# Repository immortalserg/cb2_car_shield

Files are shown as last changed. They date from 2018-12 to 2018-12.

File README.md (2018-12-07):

# cb2 car shield

Шилд для Cubieboard2 (или Banana Pi M1, M1+, M3, M2M, R2, M64, M2 Ultra, M2 Berry, Nanopi A64) и LCD панели LQ123K1LG03 под этот шлейф (разъем J1) или этот шлейф (разъем J2)

### Разъемы для подключения LVDS

Omron XF2M-4015-1A - 40 контактный BananaPi M3, A64, M2B, M2U, R2 (разъем J4), M1, M1+ (разъем J5)

Omron XF2M-2415-1A - 24 контактный BananaPi M2M (разъем J3)

Omron XF2M-3015-1A - 30 контактный NanoPi A64 (разъем J6)

### Описание

Разъемы Omron применены для того, чтобы не задумываться над расположением разъема так как стандартные разъемы (например Hirose) имеют одностороннее подключение шлейфа в отличии от Omron у которого двухстороннее подключение шлейфа.

Миникомпьютер предназначен для вывода информации на экран, по уарт к миникомпьютеру подключен микроконтроллер Atmel SAM3X8E (Arduino DUE) который считывает данные и по uart передает на миникомпьютер , входы к микроконтроллеру подключены через буферы MC14503B (цифровые порты 22-52), цифровые порты 8-12 можно использовать как ШИМ и 53 как I/O запаяв перемычки или как входы запаяв микросхему. Аналоговые порты 0-7 для подключения датчиков через делители.

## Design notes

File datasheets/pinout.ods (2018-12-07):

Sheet: LQ123K1LG03
LQ123K1LG03 | CB2Car | СВ2Car2 | CB2
1 | 1 | 1 | 44 | +3.3V |  | Parameter | Symbol | Min. | Typ. | Max. | Unit
2 | 2 | 2 |  | +3.3V |  | Frequency | 1/T c | 40 | 53.172 | 56 | MHz
 | 3 |  |  |  |  | Horizontal period | T H | 1420 | 1688 | 1895 | clock
 | 4 |  |  |  |  |  |  | 25.4 | 31.746 | 47.4 | μs
3 | 5 | 5 |  | GND |  | Horizontal period (High) | T Hd | 1280 | 1280 | 1280 | clock
4 | 6 | 6 |  | GND |  | Vertical period | T V | 487 | 525 | 575 | line
5 | 7 | 7 | 13 | RXIN0- | Receiver signal, CH0 (－) |  |  | - | 16.7 | - | ms
6 | 8 | 8 | 1 | RXIN0+ | Receiver signal, CH0 (＋) | Vertical period (High) | T Vd | 480 | 480 | 480 | line
7 | 9 | 13 | 2 | GND | GND
8 | 10 | 9 | 15 | RXIN1- | Receiver signal, CH1 (－)
9 | 11 | 10 | 3 | RXIN1+ | Receiver signal, CH1 (＋)
10 | 12 | 14 | 9 | GND | GND
 | 13
 | 14
11 | 15 | 11 | 17 | RXIN2- | Receiver signal, CH2 (－)
12 | 16 | 12 | 5 | RXIN2+ | Receiver signal, CH2 (＋)
 | 17
 | 18
13 | 19 |  | 20 | GND | GND
14 | 20 | 15 | 19 | RXCLK- | IN- Receiver signal, CK
15 | 21 | 16 | 7 | RXCLK+ | IN+ Receiver signal, CK
16 | 22 |  |  | GND | GND
17 | 23 | 17 | 11 | RXIN3- | Receiver signal, CH3 (－)
18 | 24 | 18 | 21 | RXIN3+ | Receiver signal, CH3 (＋)
 | 25
 | 26
19 | 27 | 19 |  | RL/UD | Horizontal/Vertical display mode select signal [Note1]
20 | 28 | 20 |  | SELLVDS | SELLVDS
 | 29
 | 30
https://ru.aliexpress.com/item/LVDS-CABLE-DF14-20-S6-double-2ch-6bit-for-12inch-15inch-lcd-panel/32624039545.html

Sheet: BPi
BananaPi |  |  |  |  |  |  |  |  |  |  |  |  |  |  |  |  | NanoPi
F2 | M1 | M1+ | M2 Zero | M2+ | M2B | M2M | M2M | M2U | M3 | M64 | P2 Zero | R1 | R2 | R64 | W2 | Zero | A64
 | A20 | A20 |  |  | R40 | A33 | R16 | R40 | A83T | A53 |  |  | MT7623N |  |  |  | A64 |  |  | Processor
 |  |  |  |  |  |  |  |  |  |  |  |  |  |  |  |  |  |  | Тип 1 |  |  | Тип 2 |  |  | Тип 3 |  |  | Тип 4 |  |  | Тип 5 |  | Тип 6
 |  |  |  |  |  |  |  |  |  |  |  |  |  |  |  |  |  |  | GPIO DIP40-254
 |  | 5 |  |  |  | 4 | 3 |  | 2 |  | 1 |  |  |  |  |  | 6 | 1 |  | 3.3V |  |  | 3.3V |  |  | 3.3V |  |  | 3.3V |  |  | 3.3V |  | SYS_3.3V
 |  | 5 |  |  |  | 4 | 3 |  | 2 |  | 1 |  |  |  |  |  | 6 | 2 |  | 5.0V |  |  | 5.0V |  |  | 5.0V |  |  | 5.0V |  |  | 5.0V |  | VDD_5V
 |  | 5 |  |  |  | 4 | 3 |  | 2 |  | 1 |  |  |  |  |  | 6 | 3 | PA12 | TWI0-SDA |  | PH5 | TWI2-SDA |  | PH5 | TWI1-SDA |  | PH5 | SDA |  | PB21 | TWI2-SDA | E15 | I2C2_SDA
 |  | 5 |  |  |  | 4 | 3 |  | 2 |  | 1 |  |  |  |  |  | 6 | 4 |  | 5.0V |  |  | 5.0V |  |  | 5.0V |  |  | 5.0V |  |  | 5.0V |  | VDD_5V
 |  | 5 |  |  |  | 4 | 3 |  | 2 |  | 1 |  |  |  |  |  | 6 | 5 | PA11 | TWI0-SCK |  | PH4 | TWI2-SCK |  | PH4 | TWI1-SCK |  | PH4 | SCL |  | PB20 | TWI2-SCK | E14 | I2C2_SCL
 |  | 5 |  |  |  | 4 | 3 |  | 2 |  | 1 |  |  |  |  |  | 6 | 6 |  | GND |  |  | GND |  |  | GND |  |  | GND |  |  | GND |  | GND
 |  | 5 |  |  |  | 4 | 3 |  | 2 |  | 1 |  |  |  |  |  | 6 | 7 | PA6 | PWM1 |  | PL10 | S-PWM |  | PH1 | PWM1 |  | PH1 | PWM |  | PI3 | PWM1 | D7
 |  | 5 |  |  |  | 4 | 3 |  | 2 |  | 1 |  |  |  |  |  | 6 | 8 | PA13 | UART3-TX | SPI1-CS | PB0 | UART2-TX |  | PB0 | UART2-TX |  | PB0 | UART0-TX |  | PH0 | UART3\_TX | H4 | UART3-TX
 |  | 5 |  |  |  | 4 | 3 |  | 2 |  | 1 |  |  |  |  |  | 6 | 9 |  | GND |  |  | GND |  |  | GND |  |  | GND |  |  | GND |  | GND
 |  | 5 |  |  |  | 4 | 3 |  | 2 |  | 1 |  |  |  |  |  | 6 | 10 | PA14 | UART3-RX | SPI1-CLK | PB1 | UART2-RX |  | PB1 | UART2-RX |  | PB1 | UART0-RX |  | PH1 | UART3\_RX | H5 | UART3-RX
 |  | 5 |  |  |  | 4 | 3 |  | 2 |  | 1 |  |  |  |  |  | 6 | 11 | PA1 | UART2-RX |  | PC4 | PC4 |  | PH6 | UART3\_TX |  | PH6 | UART3_TX |  | PI19 | UART2\_RX | B0 | UART2-TX
 |  | 5 |  |  |  | 4 | 3 |  | 2 |  | 1 |  |  |  |  |  | 6 | 12 | PA16 | UART3-CTS | SPI1-MISO | PB3 | UART2-CTS |  | PB3 | UART2-CTS |  | PG11 | PCM-BITCLK |  | PH2 | PH2 | L10 | PWM_S
 |  | 5 |  |  |  | 4 | 3 |  | 2 |  | 1 |  |  |  |  |  | 6 | 13 | PA0 | UART2-TX |  | PC7 | PC7 |  | PH7 | UART3\_RX |  | PH7 | UART3_RX |  | PI18 | UART2\_TX | L8 | I2C_S_SCL
 |  | 5 |  |  |  | 4 | 3 |  | 2 |  | 1 |  |  |  |  |  | 6 | 14 |  | GND |  |  | GND |  |  | GND |  |  | GND |  |  | GND |  | GND
 |  | 5 |  |  |  | 4 | 3 |  | 2 |  | 1 |  |  |  |  |  | 6 | 15 | PA3 | UART2-CTS |  | PC17 | PC17 |  | PG12 | AP-PCM-DOUT |  | PD21 | LVDS_V1N | IO-15 | PI17 | UART2\_CTS | L9 | I2C_S_SDA
 |  | 5 |  |  |  | 4 | 3 |  | 2 |  | 1 |  |  |  |  |  | 6 | 16 | PA15 | UART3-RTS | SPI1-MOSI | PB22 | UART2-RTS |  | PB2 | UART2-RTS |  | PB2 | UART0-RTS |  | PH20 | CAN\_TX | H6 | UART3-RTS
 |  | 5 |  |  |  | 4 | 3 |  | 2 |  | 1 |  |  |  |  |  | 6 | 17 |  | VCC-3V3 |  |  | VCC-3V3 |  |  | VCC-3V3 |  |  | 3.3V |  |  | VCC-3V3 |  | SYS_3.3V
 |  | 5 |  |  |  | 4 | 3 |  | 2 |  | 1 |  |  |  |  |  | 6 | 18 | PC4 | PC4 |  | PL8 | PL8 |  | PG11 | AP-PCM-CLK |  | PB3 | UART0-CTS |  | PH21 | CAN\_RX | H7 | UART3-CTS
 |  | 5 |  |  |  | 4 | 3 |  | 2 |  | 1 |  |  |  |  |  | 6 | 19 | PC0 | SPI0-MOSI |  | PC0 | SPI0_MOSI |  | PC0 | SPI0\_MOSI |  | PC0 | SPI-MOSI |  | PI12 | SPI0\_MOSI | C0 | SPI0-MOSI
 |  | 5 |  |  |  | 4 | 3 |  | 2 |  | 1 |  |  |  |  |  | 6 | 20 |  | GND |  |  | GND |  |  | GND |  |  | GND |  |  | GND |  | GND
 |  | 5 |  |  |  | 4 | 3 |  | 2 |  | 1 |  |  |  |  |  | 6 | 21 | PC1 | SPI0-MISO |  | PC1 | SPI0_MISO |  | PC1 | SPI0\_MISO |  | PC1 | SPI-MISO |  | PI13 | SPI0\_MISO | C1 | SPI0-MISO
 |  | 5 |  |  |  | 4 | 3 |  | 2 |  | 1 |  |  |  |  |  | 6 | 22 | PA2 | UART2-RTS |  | PL9 | PL9-EINT9 |  | PG10 | AP-PCM-SYNC |  | PD20 | IO-22 | LVDS_V1P | PI16 | UART2\_RTS | B1 | UART2-RX
 |  | 5 |  |  |  | 4 | 3 |  | 2 |  | 1 |  |  |  |  |  | 6 | 23 | PC2 | SPI0-CLK |  | PC2 | SPI0_CLK |  | PC2 | SPI0\_CLK |  | PC2 | SPI-CLK |  | PI11 | SPI0\_CLK | C2 | SPI0-CLK
 |  | 5 |  |  |  | 4 | 3 |  | 2 |  | 1 |  |  |  |  |  | 6 | 24 | PC3 | SPI0-CS |  | PC3 | SPI0_CS |  | PC3 | SPI0\_CS |  | PC3 | SPI-CE0 | SPI0_CS | PI10 | SPI0\_CS0 | C3 | SPI0-CS
 |  | 5 |  |  |  | 4 | 3 |  | 2 |  | 1 |  |  |  |  |  | 6 | 25 |  | GND |  |  | GND |  |  | GND |  |  | GND |  |  | GND |  | GND
 |  | 5 |  |  |  | 4 | 3 |  | 2 |  | 1 |  |  |  |  |  | 6 | 26 | PC7 | PC7 |  | PH10 | PH10 |  | PG13 | AP-PCM-DIN |  | PD25 | SPI-CE1 | LVDS_VCN | PI14 | SPI0\_CS1 | H8 | SPDIF-OUT
 |  | 5 |  |  |  | 4 | 3 |  | 2 |  | 1 |  |  |  |  |  | 6 | 27 | PA19 | TWI1-SDA |  | PH3 | TWI1-SDA |  | PD19 | LVDS\_V0N |  | PD19 | ID-SD | LVDS_V0N | PI1 | TWI3-SDA | H3 | I2C1_SDA
 |  | 5 |  |  |  | 4 | 3 |  | 2 |  | 1 |  |  |  |  |  | 6 | 28 | PA18 | TWI1-SCK |  | PH2 | TWI1-SCK |  | PL11 | PL11-EINT11 |  | PD24 | ID-SC | LVDS_VCP | PI0 | TWI3-SCK | H2 | I2C1_SCL
 |  | 5 |  |  |  | 4 | 3 |  | 2 |  | 1 |  |  |  |  |  | 6 | 29 | PA7 | PA7-EINT7 |  | PC18 | PC18 |  | PD18 | LVDS\_V0P |  | PD18 | IO-29 | LVDS_V0P | PB5 | I2S\_MCLK | H10
 |  | 5 |  |  |  | 4 | 3 |  | 2 |  | 1 |  |  |  |  |  | 6 | 30 |  | GND |  |  | GND |  |  | GND |  |  | GND |  |  | GND |  | GND
 |  | 5 |  |  |  | 4 | 3 |  | 2 |  | 1 |  |  |  |  |  | 6 | 31 | PA8 | PA8-EINT8 |  | PG10 | I2S1-BCLK | UART3-TX | PD21 | LVDS\_V1N |  | PD23 | IO-31 | LVDS_V2N | PB6 | I2S\_BCLK | H11
 |  | 5 |  |  |  | 4 | 3 |  | 2 |  | 1 |  |  |  |  |  | 6 | 32 | PL2 | PL2-S-EINT2 |  | PG13 | I2S1-DIN | UART3-CTS | PD23 | LVDS\_V2N |  | PD22 | IO-32 | LVDS_V2P | PB12 | I2S\_DI | D4
 |  | 5 |  |  |  | 4 | 3 |  | 2 |  | 1 |  |  |  |  |  | 6 | 33 | PA9 | PA9-EINT9 |  | PG11 | I2S1-LRCK | UART3-RX | PD20 | LVDS\_V1P |  | PD27 | IO-33 | LVDS_V3N | PB7 | I2S\_LRCK | D5
 |  | 5 |  |  |  | 4 | 3 |  | 2 |  | 1 |  |  |  |  |  | 6 | 34 |  | GND |  |  | GND |  |  | GND |  |  | GND |  |  | GND |  | GND
 |  | 5 |  |  |  | 4 | 3 |  | 2 |  | 1 |  |  |  |  |  | 6 | 35 | PA100 | PA10-EINT10 |  | PG12 | I2S1-DOUT | UART3-RTS | PD25 | LVDS\_VCN |  | PG10 | PCM-LRCLK | PCM-SYNC | PB8 | I2S\_DO0 | D3 | SPI1-MISO
 |  | 5 |  |  |  | 4 | 3 |  | 2 |  | 1 |  |  |  |  |  | 6 | 36 | PL4 | PL4-S-EINT4 |  | PE5 | PE5 |  | PD22 | LVDS\_V2P |  | PD26 | IO-36 | LVDS_V3P | PI21 | UART7\_RX | D0 | SPI1-CS
 |  | 5 |  |  |  | 4 | 3 |  | 2 |  | 1 |  |  |  |  |  | 6 | 37 | PA17 | PA17-EINT17 | SPDIF-OUT | PE4 | PE4 |  | PD24 | LVDS\_VCP |  | PL11 | IO-37 | EINT11 | PB3 | IR0\_TX | D6
 |  | 5 |  |  |  | 4 | 3 |  | 2 |  | 1 |  |  |  |  |  | 6 | 38 | PA21 | PA21-EINT21 |  | PE18 | OWA-DOUT |  | PD27 | LVDS\_V3N |  | PG13 | PCM-DIN |  | PI20 | UART7\_TX | D2 | SPI1-MOSI
 |  | 5 |  |  |  | 4 | 3 |  | 2 |  | 1 |  |  |  |  |  | 6 | 39 |  | GND |  |  | GND |  |  | GND |  |  | GND |  |  | GND |  | GND
 |  | 5 |  |  |  | 4 | 3 |  | 2 |  | 1 |  |  |  |  |  | 6 | 40 | PA20 | PA20-EINT20 |  | PE19 | PE19 |  | PD26 | LVDS\_V3P |  | PG12 | PCM-DO |  | PB13 | SPDIF\_DO | D1 | SPI1-CLK
 |  |  |  |  |  |  |  |  |  |  |  |  |  |  |  |  |  |  | DSI FPC24-05PH-BOT
 |  |  |  |  |  | 2 | 1 |  |  |  |  |  |  |  |  |  |  | 1 |  | DSI-D0N |  |  | DSI-D0N
 |  |  |  |  |  | 2 | 1 |  |  |  |  |  |  |  |  |  |  | 2 |  | DSI-D0P |  |  | DSI-D0P
 |  |  |  |  |  | 2 | 1 |  |  |  |  |  |  |  |  |  |  | 3 |  | DSI-D1N |  |  | DSI-D1N
 |  |  |  |  |  | 2 | 1 |  |  |  |  |  |  |  |  |  |  | 4 |  | DSI-D1P |  |  | DSI-D1P
 |  |  |  |  |  | 2 | 1 |  |  |  |  |  |  |  |  |  |  | 5 |  | DSI-CKN |  |  | DSI-CKN
 |  |  |  |  |  | 2 | 1 |  |  |  |  |  |  |  |  |  |  | 6 |  | DSI-CKP |  |  | DSI-CKP
 |  |  |  |  |  | 2 | 1 |  |  |  |  |  |  |  |  |  |  | 7 |  | DSI-D2N |  |  | DSI-D2N
 |  |  |  |  |  | 2 | 1 |  |  |  |  |  |  |  |  |  |  | 8 |  | DSI-D2P |  |  | DSI-D2P
 |  |  |  |  |  | 2 | 1 |  |  |  |  |  |  |  |  |  |  | 9 |  | DSI-D3N |  |  | DSI-D3N
 |  |  |  |  |  | 2 | 1 |  |  |  |  |  |  |  |  |  |  | 10 |  | DSI-D3P |  |  | DSI-D3P
 |  |  |  |  |  | 2 | 1 |  |  |  |  |  |  |  |  |  |  | 11 |  | NC
 |  |  |  |  |  | 2 | 1 |  |  |  |  |  |  |  |  |  |  | 12 |  | NC
 |  |  |  |  |  | 2 | 1 |  |  |  |  |  |  |  |  |  |  | 13 | PH3 | TP-SDA |  |  | TP-SDA
 |  |  |  |  |  | 2 | 1 |  |  |  |  |  |  |  |  |  |  | 14 | PH2 | TP-SCK |  |  | TP-SCK
 |  |  |  |  |  | 2 | 1 |  |  |  |  |  |  |  |  |  |  | 15 | PB5 | TP-INT |  |  | TP-INT
 |  |  |  |  |  | 2 | 1 |  |  |  |  |  |  |  |  |  |  | 16 | PB6 | TP-RST |  |  | TP-RST
 |  |  |  |  |  | 2 | 1 |  |  |  |  |  |  |  |  |  |  | 17 | PL4 | LCD-BL-EN |  |  | LCD-BL-EN
 |  |  |  |  |  | 2 | 1 |  |  |  |  |  |  |  |  |  |  | 18 | PL5 | LCD-RST |  |  | LCD-RST
 |  |  |  |  |  | 2 | 1 |  |  |  |  |  |  |  |  |  |  | 19 | PB7 | LCD-PWR-EN |  |  | LCD-PWR-EN
 |  |  |  |  |  | 2 | 1 |  |  |  |  |  |  |  |  |  |  | 20 | PH0 | LCD-PWM |  |  | LCD-PWM
 |  |  |  |  |  | 2 | 1 |  |  |  |  |  |  |  |  |  |  | 21 |  | GND |  |  | GND
 |  |  |  |  |  | 2 | 1 |  |  |  |  |  |  |  |  |  |  | 22 |  | GND |  |  | GND
 |  |  |  |  |  | 2 | 1 |  |  |  |  |  |  |  |  |  |  | 23 |  | PS |  |  | PS
 |  |  |  |  |  | 2 | 1 |  |  |  |  |  |  |  |  |  |  | 24 |  | PS |  |  | PS
 |  |  |  |  |  |  |  |  |  |  |  |  |  |  |  |  |  |  | DSI FPC40-05PH-BOT
 | 3 | 3 |  |  | 4 |  |  | 4 | 1 | 2 |  |  | 5 |  |  |  |  | 1 |  | VCC-MIPI |  |  | VCC |  |  | IPSOUT\(5V output\) |  |  | VCC-3V3 |  |  | VCC-3V3
 | 3 | 3 |  |  | 4 |  |  | 4 | 1 | 2 |  |  | 5 |  |  |  |  | 2 |  | IPSOUT |  |  | IPSOUT |  | PI1 | TWI3-SDA |  |  | IPSOUT |  |  | VCC-5V
 | 3 | 3 |  |  | 4 |  |  | 4 | 1 | 2 |  |  | 5 |  |  |  |  | 3 |  | VCC-MIPI |  |  | VCC |  |  | IPSOUT\(5V output\) |  |  | VCC-3V3 |  |  | VCC-3V3
 | 3 | 3 |  |  | 4 |  |  | 4 | 1 | 2 |  |  | 5 |  |  |  |  | 4 |  | IPSOUT |  |  | IPSOUT |  | PI0 | TWI3-SCK |  |  | IPSOUT |  |  | VCC-5V
 | 3 | 3 |  |  | 4 |  |  | 4 | 1 | 2 |  |  | 5 |  |  |  |  | 5 |  | GND |  |  | GND |  |  | GND |  |  | GND |  |  | GND
 | 3 | 3 |  |  | 4 |  |  | 4 | 1 | 2 |  |  | 5 |  |  |  |  | 6 |  | IPSOUT |  |  | IPSOUT |  | PH7 | LCD0-IO0 |  |  | IPSOUT |  |  | VCC-5V
 | 3 | 3 |  |  | 4 |  |  | 4 | 1 | 2 |  |  | 5 |  |  |  |  | 7 |  | GND |  |  | GND |  | PH12 | LCDIO-03 |  |  | GND |  |  | GND
 | 3 | 3 |  |  | 4 |  |  | 4 | 1 | 2 |  |  | 5 |  |  |  |  | 8 |  | IPSOUT |  |  | IPSOUT |  | PH8 | LCD0-IO1 |  |  | IPSOUT |  |  | VCC-5V
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

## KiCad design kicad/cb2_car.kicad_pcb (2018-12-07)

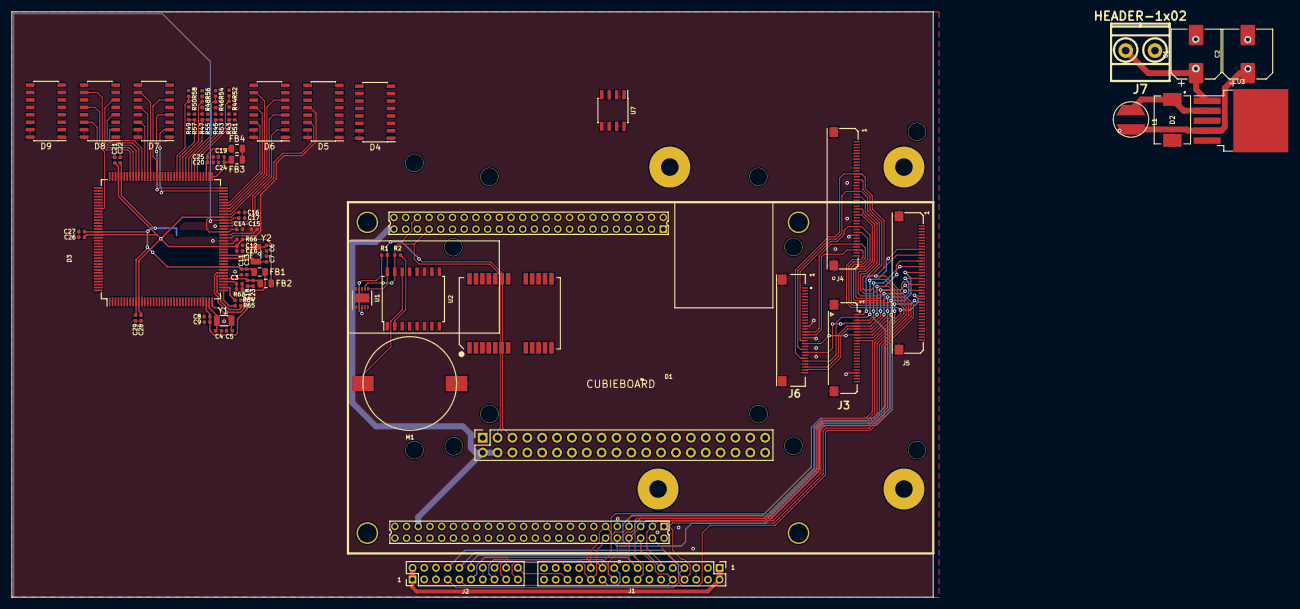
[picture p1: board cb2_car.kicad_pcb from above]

Board: 2 copper layers, 157.4 x 100.0 mm, 82 parts (0 on the bottom side), 81 nets.

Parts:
AE1: ANTENNA; LQ123K1LG03
C1: 680 uF; CP_Elec_8x10
C2: 220 uF; CP_Elec_8x10
C3, C4, C5, C6, C7: 22 pF; C_0402_1005Metric
C8, C12, C13, C14, C15, C16, C17, C18, C19, C20, C21, C22, C26, C27, C28, C29: 100 nF; C_0402_1005Metric
C9, C10, C11, C23, C24, C25: 10 uF; C_0402_1005Metric
D1: BananaPi; BananaPi_m2m_v5
D2: SS34; DIOM7959X265
D3: ATSAM3X8EA-AU; LQFP-144_20x20mm_P0.5mm
D4, D5, D6, D7, D8, D9: MC14503B; SOIC-16_3.9x9.9mm_P1.27mm
FB1, FB2, FB3, FB4: MH2029-300Y; C_0805_2012Metric
J1: Conn_02x15_Odd_Even; PinHeader_2x16_P2.00mm_Vertical
J2: HEADER-2x10; PinHeader_2x10_P2.00mm_Vertical
J3: Omron XF2M-2415-1A; Omron_XF2M-2415-1A
J4, J5: Omron XF2M-4015-1A; Omron_XF2M-4015-1A
J6: Omron XF2M-3015-1A; Omron_XF2M-3015-1A
J7: HEADER-1x02; mkds_1,5-2
L1: 33 uH; CD54
M1: CR1220SMD; cr1220_smd
R1, R2: 4,7 K; R_0402_1005Metric
R43, R44, R45, R46, R47, R48, R49, R50: 47k; R_0402_1005Metric
R51, R52, R53, R54, R55, R56, R57, R58, R66: 100k; R_0402_1005Metric
R63: 6k8 1%; R_0402_1005Metric
R64, R65: 39R 1%; R_0402_1005Metric
U1: MMA7660FCR1_Obsolete; DFN-10-1EP_3x3mm_P0.5mm_EP1.55x2.48mm
U2: DS3231_SO; SOIC-16W_7.5x10.3mm_P1.27mm
U3: LM2596S-5; TO-263-5_TabPin3
U4: MOUDLE-GPS-NEO-6M(24P-16X12.2MM); Neo_GPS24P-SMD-1.1-16X12.2MM
U7: DS2482; SOIC-8_3.9x4.9mm_P1.27mm
X1: CUBIEBOARD; Cubieboard2
Y1: 12MHz; Crystal_SMD_3215-2Pin_3.2x1.5mm
Y2: 32.768Khz; Crystal_SMD_3215-2Pin_3.2x1.5mm

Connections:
+3.3V: C10.2, C12.2, C14.2, C16.2, C21.2, C26.2, C28.2, D3.11, D3.52, D3.57, D3.62, D3.105, D3.125, D4.8, D5.8, D6.8, D7.8, D8.8, D9.8, FB2.1, FB3.1, FB4.1, J1.1, J1.2, J2.1, J2.2, R1.1, R2.1, R66.2, U1.3, U1.9, U2.2
+5V: C2.1, D1.2, D1.4, L1.2, U3.4, U7.1, X1.43, X1.49
AVDREF: C20.2, C25.2, D3.75, FB4.2
GND: C1.2, C2.2, C3.1, C4.2, C5.2, C6.2, C7.2, C8.1, C9.1, C10.1, C11.1, C12.1, C13.1, C14.1, C15.1, C16.1, C17.1, C18.1, C19.1, C20.1, C21.1, C22.1, C23.1, C24.1, C25.1, C26.1, C27.1, C28.1, C29.1, D1.6, D1.9, D1.14, D1.20, D1.25, D1.30, D1.34, D1.39, D2.2, D3.12, D3.33, D3.44, D3.54, D3.58, D3.74, D3.106, D3.126, D4.1, D4.15, D4.16, D5.1, D5.15, D5.16, D6.1, D6.15, D6.16, D7.1, D7.15, D7.16, D8.1, D8.15, D8.16, D9.1, D9.15, D9.16, J1.5, J1.6, J1.9, J1.12, J1.19, J1.22, J2.5, J2.6, J2.13, J2.14, J3.21, J3.22, J3.25, J3.26, J4.5, J4.7, J4.10, J4.16, J4.22, J4.25, J4.28, J4.33, J4.34, J4.37, J4.40, J4.41, J4.42, J5.5, J5.24, J5.41, J5.42, J6.14, J6.15, J6.18, J6.21, J6.24, J6.27, J6.30, J6.31, J6.32, J7.1, M1.1, R43.1, R44.1, R45.1, R46.1, R47.1, R48.1, R49.1, R50.1, R63.2, U1.4, U1.8, U1.11, U2.13, U3.3, U3.5, U4.10, U4.12, U4.13, U7.3, U7.7, U7.8, X1.2, X1.9, X1.20, X1.38, X1.42, X1.67, X1.68, X1.73, X1.85
unnamed: C1.1, J7.2, U3.1
unnamed: C3.2, D3.40, R63.1
unnamed: C4.1, D3.35, Y1.1
unnamed: C5.1, D3.36, Y1.2
unnamed: C6.1, D3.49, Y2.1
unnamed: C7.1, D3.48, Y2.2
unnamed: C8.2, C9.2, D3.34, FB1.2
unnamed: D2.1, L1.1, U3.2
unnamed: D3.37, R65.2
unnamed: D3.38, R64.2
unnamed: D3.42, R65.1
unnamed: D3.43, R64.1
unnamed: D3.53, R66.1
unnamed: M1.2, U2.14
RL_UD: J1.27, J2.19
RX: D1.10, U4.20
RXCLK+: J1.21, J2.16, J3.6, J4.26, J5.21, J6.29, X1.7
RXCLK-: J1.20, J2.15, J3.5, J4.24, J5.23, J6.28, X1.10
RXIN0+: J1.8, J2.8, J3.2, J4.14, J5.9, J6.26, X1.1
RXIN0-: J1.7, J2.7, J3.1, J4.12, J5.11, J6.25, X1.4
RXIN1+: J1.11, J2.10, J3.4, J4.20, J5.13, J6.23, X1.3
RXIN1-: J1.10, J2.9, J3.3, J4.18, J5.15, J6.22, X1.6
RXIN2+: J1.16, J2.12, J3.8, J4.32, J5.17, J6.20, X1.5
RXIN2-: J1.15, J2.11, J3.7, J4.30, J5.19, J6.19, X1.8
RXIN3+: J1.24, J2.18, J3.10, J4.38, J5.25, J6.17, X1.12
RXIN3-: J1.23, J2.17, J3.9, J4.36, J5.27, J6.16, X1.11
SCL: D1.5, R1.2, U1.6, U2.16, X1.54
SDA: D1.3, R2.2, U1.7, U2.15, X1.55
SELLVDS: J1.28, J2.20
TX: D1.8, U4.21
VDDANA: C19.2, C24.2, D3.73, FB3.2
VDDOUT: C11.2, C13.2, C15.2, C17.2, C22.2, C27.2, C29.2, D3.10, D3.45, D3.56, D3.61, D3.104, D3.124, FB1.1
VDDUTMI: C18.2, C23.2, D3.41, FB2.2
a0: D3.78, R43.2, R51.2
a1: D3.79, R44.2, R52.2
a2: D3.80, R45.2, R53.2
a3: D3.81, R46.2, R54.2
a4: D3.82, R47.2, R55.2
a5: D3.83, R48.2, R56.2
a6: D3.84, R49.2, R57.2
a7: D3.85, R50.2, R58.2
d8: D3.133, D9.4
d9: D3.132, D9.6
d10: D3.111, D9.10
d11: D3.20, D9.14
d12: D3.21, D9.12
d23: D3.7, D4.2
d24: D3.8, D4.4
d25: D3.13, D4.6
d26: D3.14, D4.10
d27: D3.15, D4.12
d28: D3.16, D4.14
d29: D3.19, D5.2
d30: D3.22, D5.4
d31: D3.26, D5.6
d32: D3.32, D5.10
d33: D3.55, D5.12
d34: D3.59, D5.14
d35: D3.60, D6.2
d36: D3.116, D8.14
d37: D3.63, D6.4
d38: D3.64, D6.6
d39: D3.65, D6.10
d40: D3.66, D6.12
d41: D3.67, D6.14
d42: D3.71, D7.2
d43: D3.72, D7.4
d44: D3.101, D8.12
d45: D3.100, D8.10
d46: D3.99, D8.6
d47: D3.98, D8.4
d48: D3.97, D8.2
d49: D3.96, D7.14
d50: D3.95, D7.12
d51: D3.94, D7.10
d52: D3.92, D7.6
d53: D3.140, D9.2
